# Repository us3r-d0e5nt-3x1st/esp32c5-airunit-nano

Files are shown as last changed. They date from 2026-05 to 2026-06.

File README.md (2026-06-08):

i think it's ready and it should work in the current state, but i still need to check if everything works in practice and write some kind of documentation for it. <br><br>
when you're downloading the files, please use either the main branch > code > download zip, or the project, photos and gerber zip files in the newest release, and not anything in the tags or the source code in the release, because they are older (broken) versions of the project





resources taken mostly from seeed's wiki for xiao s3 sense board + the amazing hx-esp32-cam-fpv project + the esp-cam schematic + the esp32-c5-wroom-1u datasheet + some weird random websites

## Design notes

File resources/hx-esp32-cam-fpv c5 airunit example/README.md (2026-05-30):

it's all documented here, i'm gonna make my design as pin-to-pin compatible with this as possible: https://github.com/RomanLut/hx-esp32-cam-fpv/blob/e0f3d50c493b3d2b5f32726006f0b232bfb88d4a/doc/esp32c5_air_unit.md

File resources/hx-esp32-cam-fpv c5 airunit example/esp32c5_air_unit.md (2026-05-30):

# Building esp32c5 air unit

Unfortunately, there are currently no **esp32c5** boards on the market with a good form factor and a proper camera connector. Using an **esp32c5** as an air unit requires advanced hardware skills and custom assembly. For this reason, the **esp32s3sense** remains the best choice for an air unit for now.

## esp32c5 proof-of-concept air unit

Air unit can be built using **esp32-c5-devkit-c1-N8R4** board, **BY-OV5640** camera adapter and microSD card adapter.

esp32c5_air_unit

Camera and SD card wires should be as short as possible (2-3cm).

**esp32-c5-devkit-c1** board should have at least 4Mb RAM (N8R**4** or more).

esp32c5_air_unit

## esp32c5 DIY air unit

A better air unit can be made using **esp32-c5-wroom-n16-r8** module,  **BY-OV5640** camera adapter and microSD card adapter.
PCB is not designed yet. Module, linear regulator, resistors and capacitors are soldered to piece of copper-clad laminate.

esp32c5_air_unit

esp32c5_air_unit

(on the photo above pcb is marked BY-OV2640 but parts (oscillator, linear regulator) are soldered for BY-OV5640)

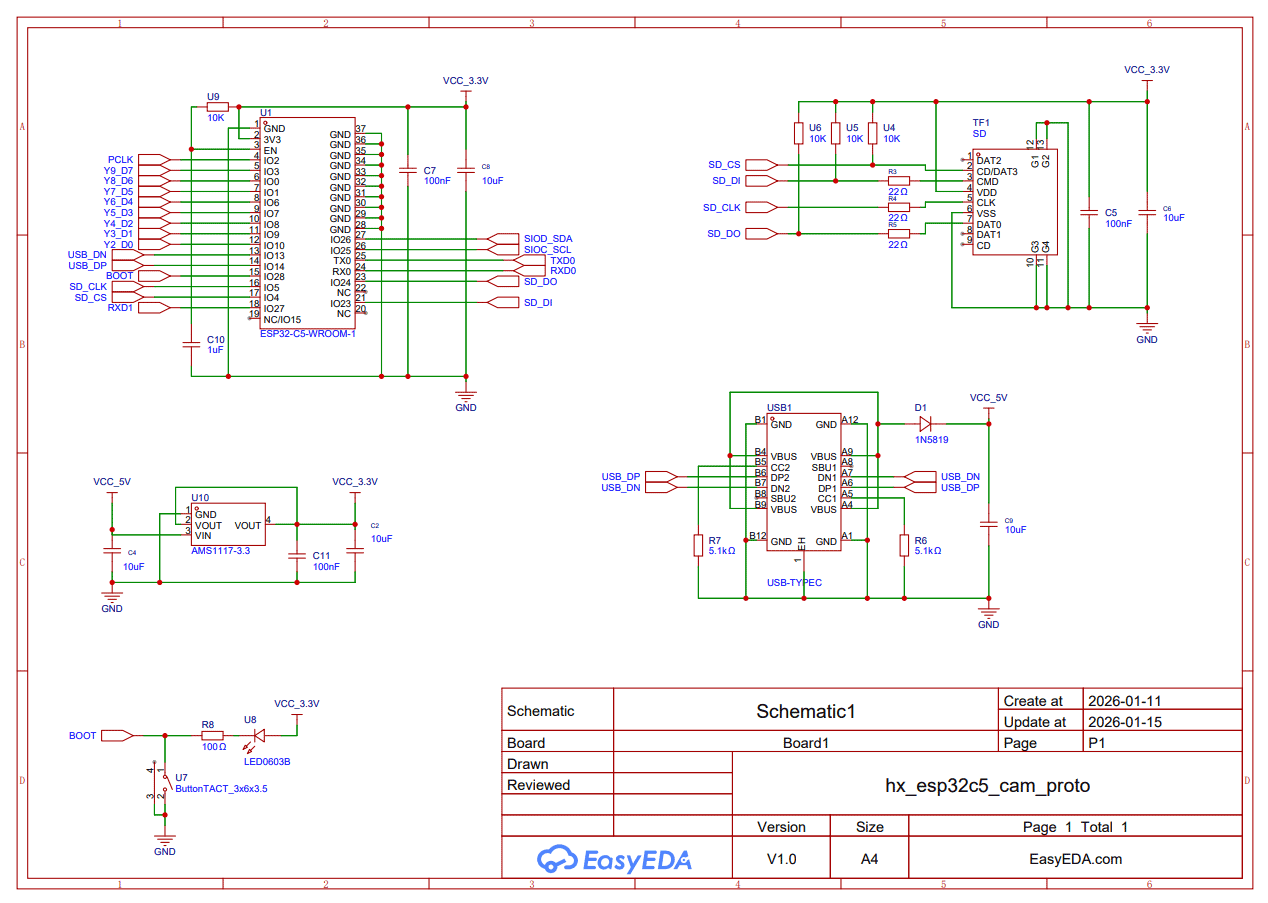
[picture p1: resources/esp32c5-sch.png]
esp32c5_air_unit


[Schematics PDF](/doc/datasheets/esp32c5-prototype-eda.pdf)

[Project EasyEDA](/doc/EasyEDA/hx_esp32c5_cam_proto.eprj)

[3d Printed case on Thingiverse](https://www.thingiverse.com/thing:7292453)

esp32c5_air_unit

esp32c5_air_unit

Size comparison with esp32s3sense:

esp32c5_air_unit

**esp32c5** 1280x720 25fps streaming, recorded on GS:

https://github.com/user-attachments/assets/3dfc3725-5c03-43d9-bf62-a5a76a4a5fef

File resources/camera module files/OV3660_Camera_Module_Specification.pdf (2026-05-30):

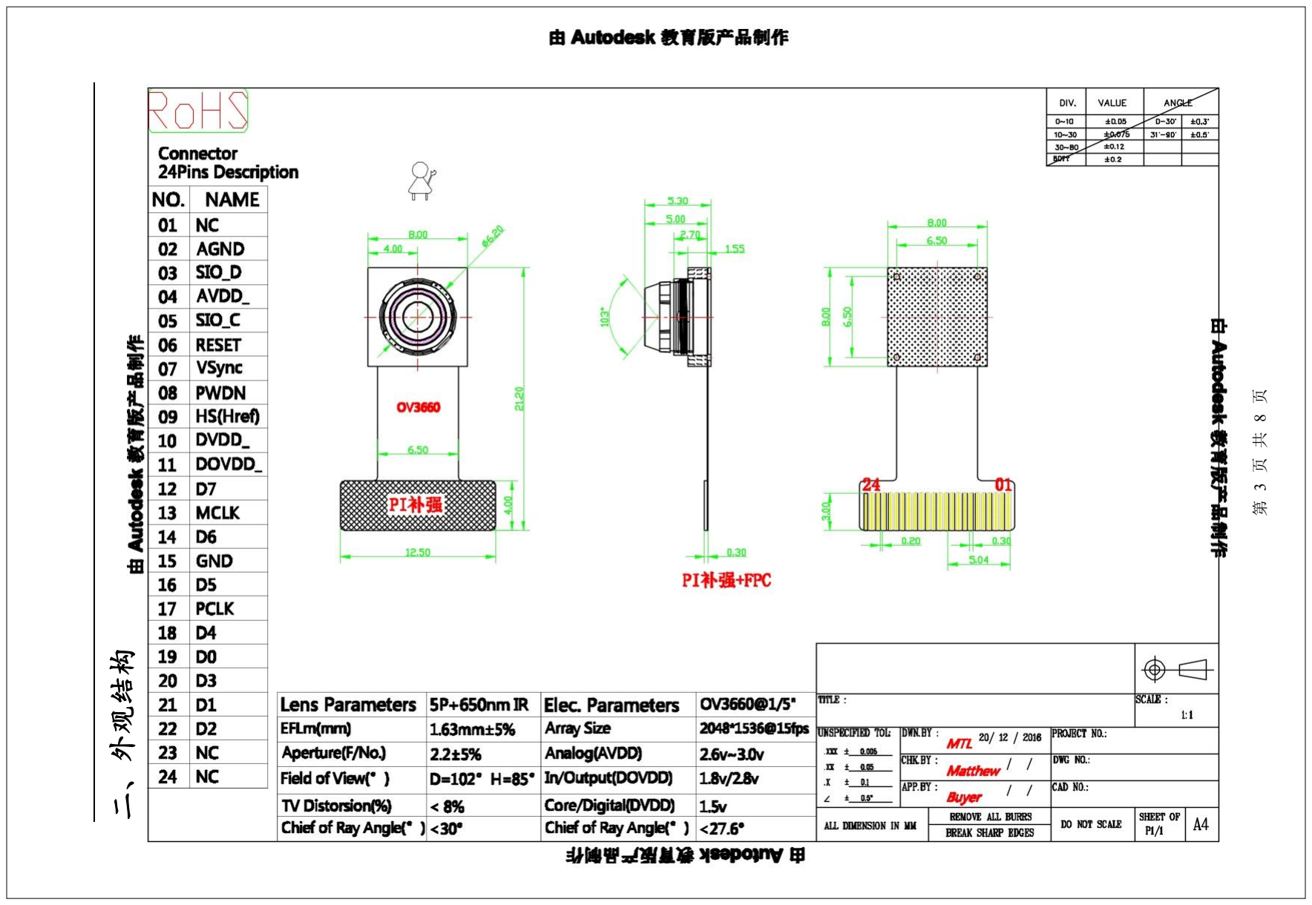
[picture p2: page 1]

## 二、外观结构

第 3 页 共 8 页

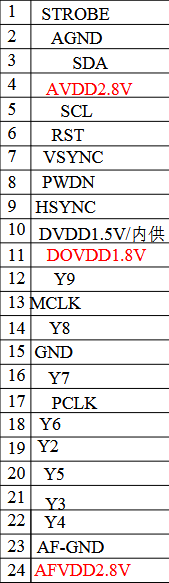
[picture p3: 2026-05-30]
resources/ov5640_pinout.PNG

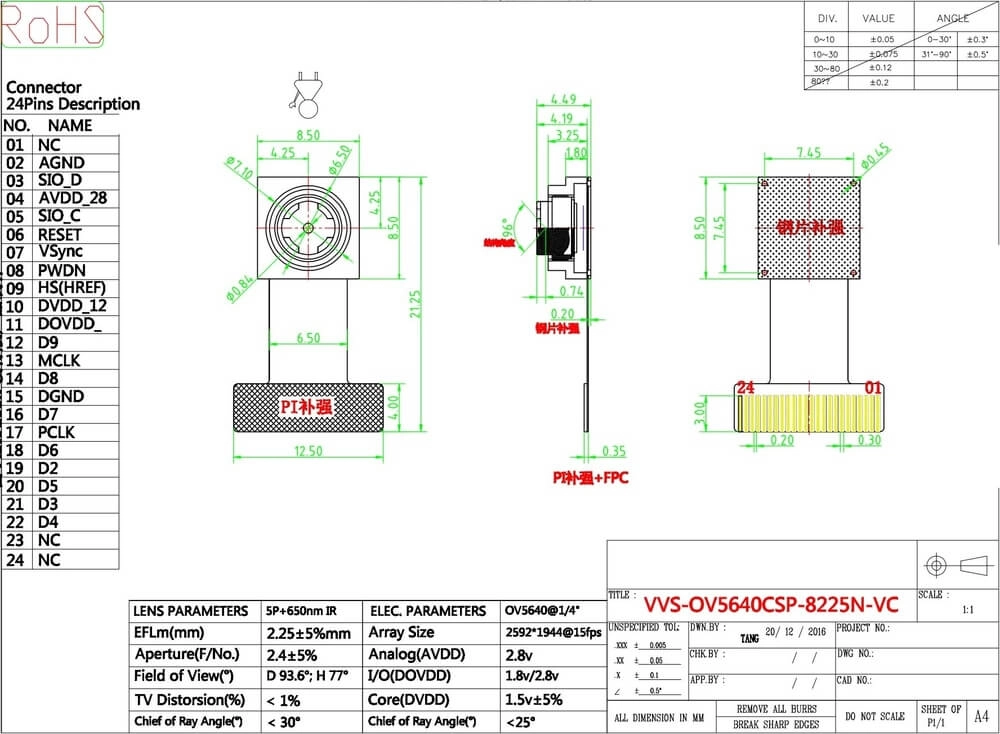
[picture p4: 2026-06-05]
resources/camera module files/ov5460-dimensions.webp

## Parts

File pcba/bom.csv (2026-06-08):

Reference | Qty | Value | Footprint | JLCPCB
C1,C6 | 2 | 100nF 50V | Capacitor_SMD:C_0603_1608Metric | C14663
C2,C3,C4,C5,C8 | 5 | 10uF 10V | Capacitor_SMD:C_0603_1608Metric | C19702
D1 | 1 | RED | LED_SMD:LED_0603_1608Metric | C2286
J1 | 1 | FPC0.5mm-24P | Connector_FFC-FPC:TE_2-1734839-4_1x24-1MP_P0.5mm_Horizontal | C5362165
J8 | 1 | TF-021B-H265 | 0475710001:MOLEX_0475710001 | C498185
L1 | 1 | FHD252010S-100MT | Inductor_SMD:L_Changjiang_FNR252010S | C602007
R1,R6 | 2 | 47kR | Resistor_SMD:R_0603_1608Metric | C25600
R2 | 1 | 12kR | Resistor_SMD:R_0603_1608Metric | C22790
R3 | 1 | 220R | Resistor_SMD:R_0603_1608Metric | C1226
SW1 | 1 | EVQP7C01P | Button_Switch_SMD:SW_SPST_EVQP7C | C388883
U1 | 1 | MT3406 | Package_TO_SOT_SMD:TSOT-23-5 | C22462728

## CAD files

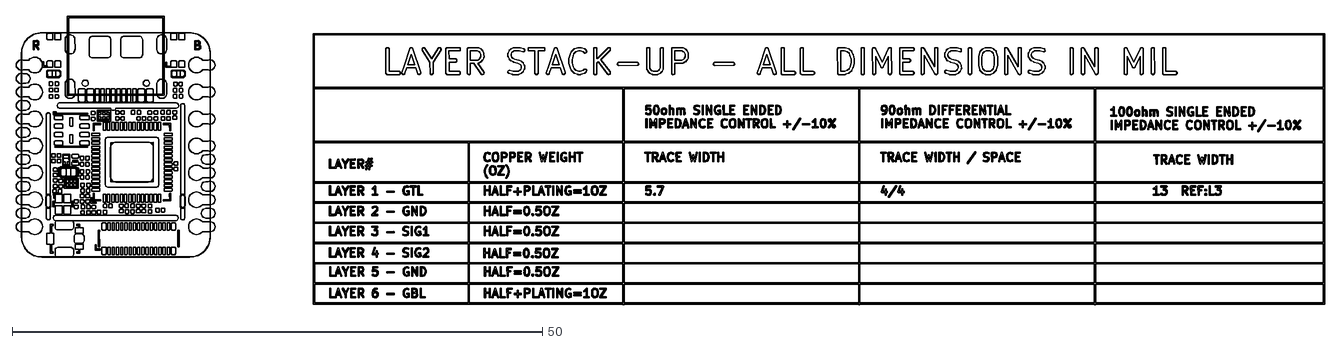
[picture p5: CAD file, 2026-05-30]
resources/xiao s3 resources/s3sense-dimensions.dxf
123.4 x 27.2

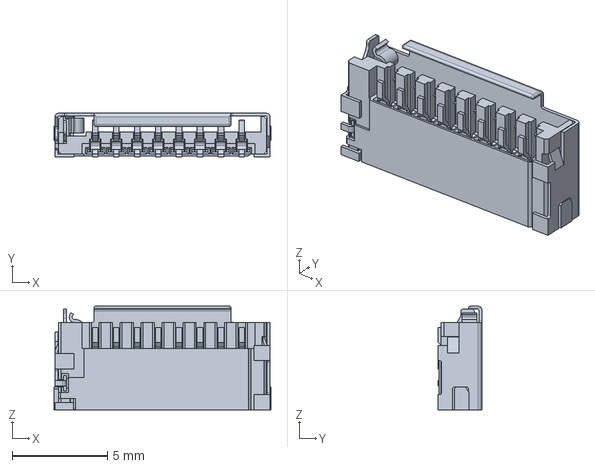
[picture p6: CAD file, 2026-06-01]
project/0475710001/0475710001.stp
11.4 x 2.30 x 5.45 mm

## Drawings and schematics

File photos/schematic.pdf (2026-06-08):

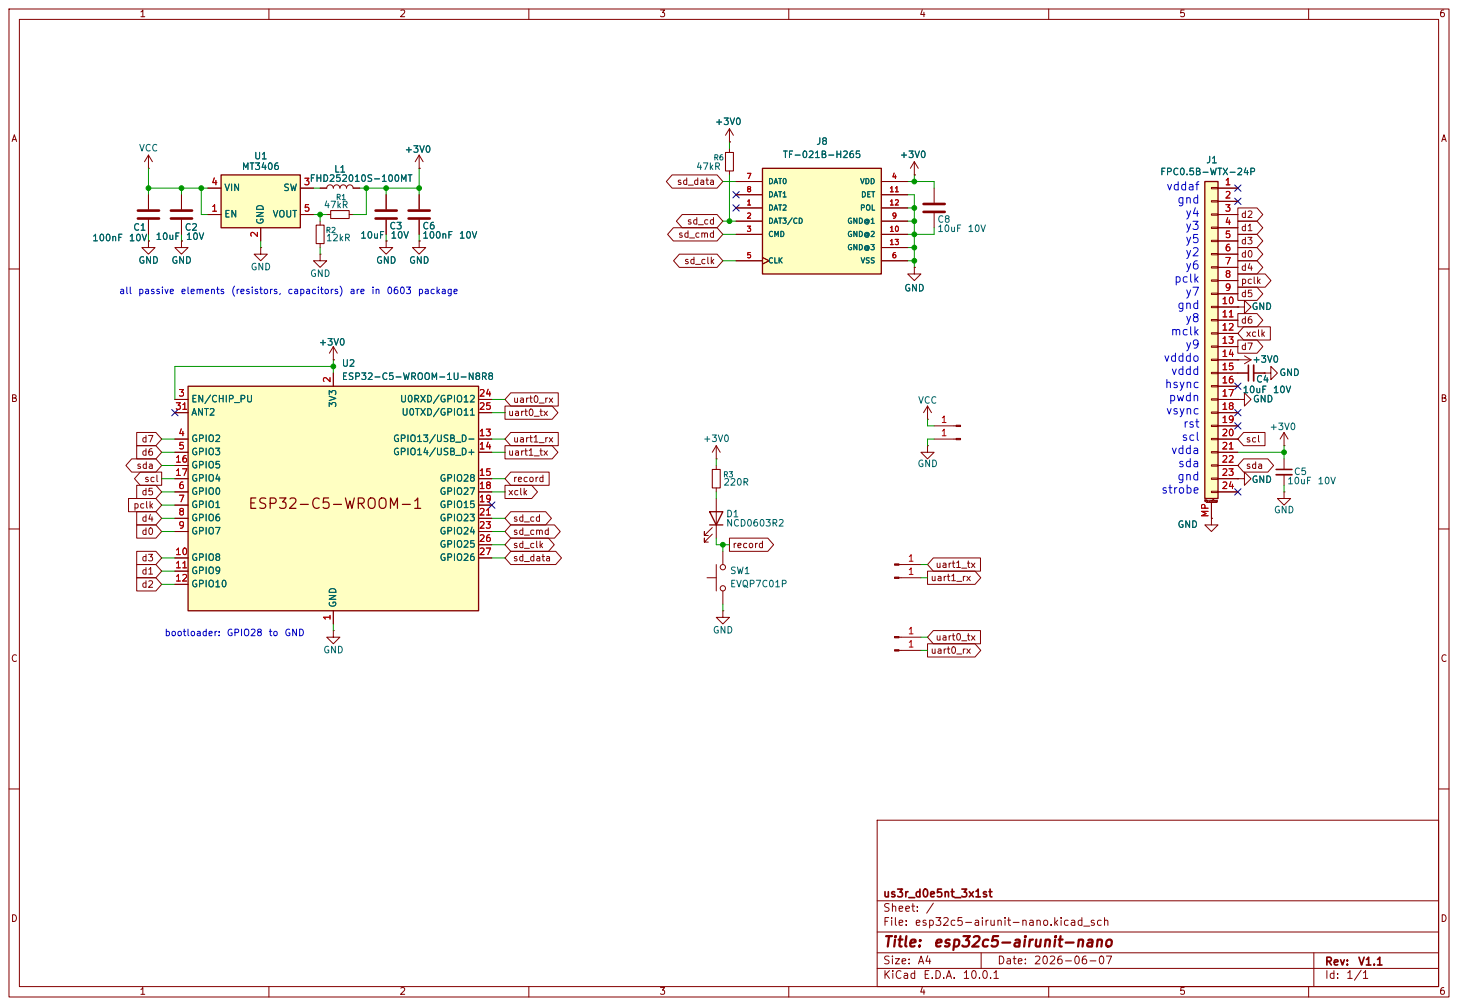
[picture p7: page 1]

uart0_rx uart0_tx uart1_rx uart1_tx all passive elements (resistors, capacitors) are in 0603 package bootloader: GPIO28 to GND

Size: A4 | Rev: V1.1
KiCad E.D.A. 10.0.1 | Id: 1/1

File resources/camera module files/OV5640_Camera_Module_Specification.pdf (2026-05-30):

## 深圳市铭嘉影光电有限公司

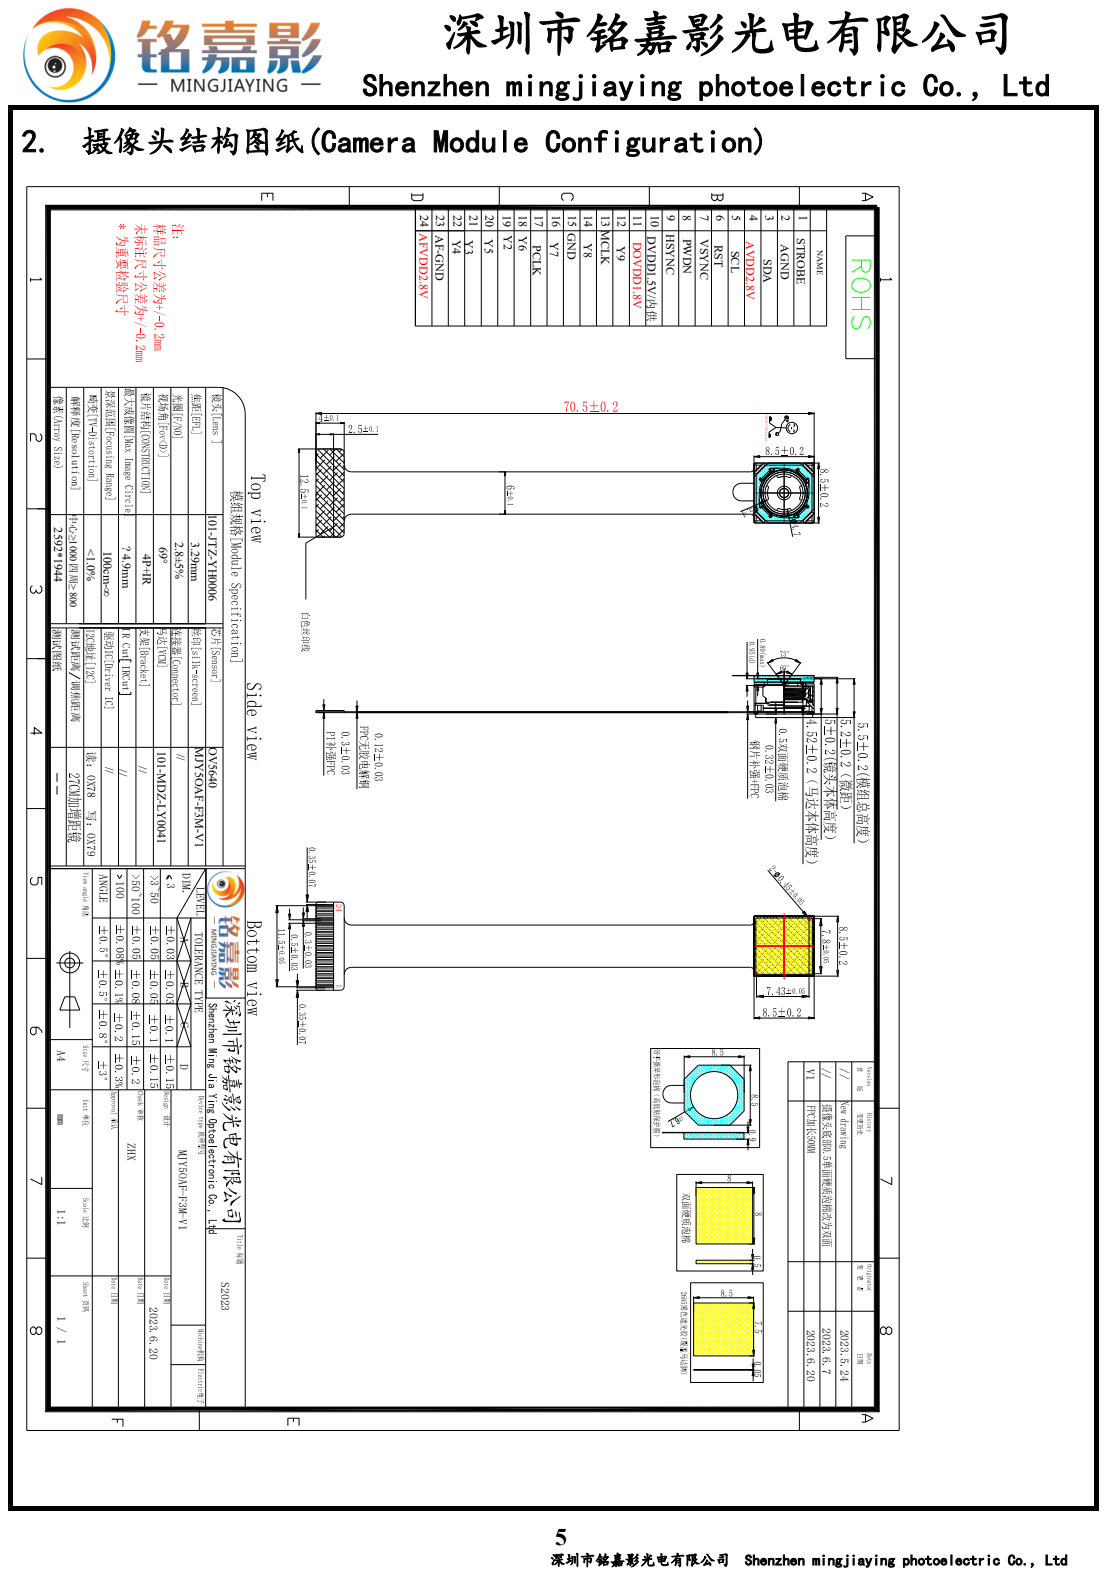
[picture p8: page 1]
TOLERANCE TYPE; ANGLE; LEVEL; DIM. A C D; 101-MDZ-LY0041; 101-JTZ-YH0006; MJY5OAF-F3M-V1; ZHX; AGND 2; SDA 3; AVDD2.8V; STROBE; VSYNC; DVDD1.5V/内供; 11 DOVDD1.8V; 13 MCLK; GND; 23 AF-GND; 24 AFVDD2.8V; SCL; NAME; RST; PWDN; HSYNC; PCLK; 测试图纸

Shenzhen mingjiaying photoelectric Co., Ltd

2. 摄像头结构图纸(Camera Module Configuration)

解释度[Resolution] 测试距离 调焦距离

IR Cut IRCut

深圳市铭嘉影光电有限公司 Shenzhen mingjiaying photoelectric Co., Ltd

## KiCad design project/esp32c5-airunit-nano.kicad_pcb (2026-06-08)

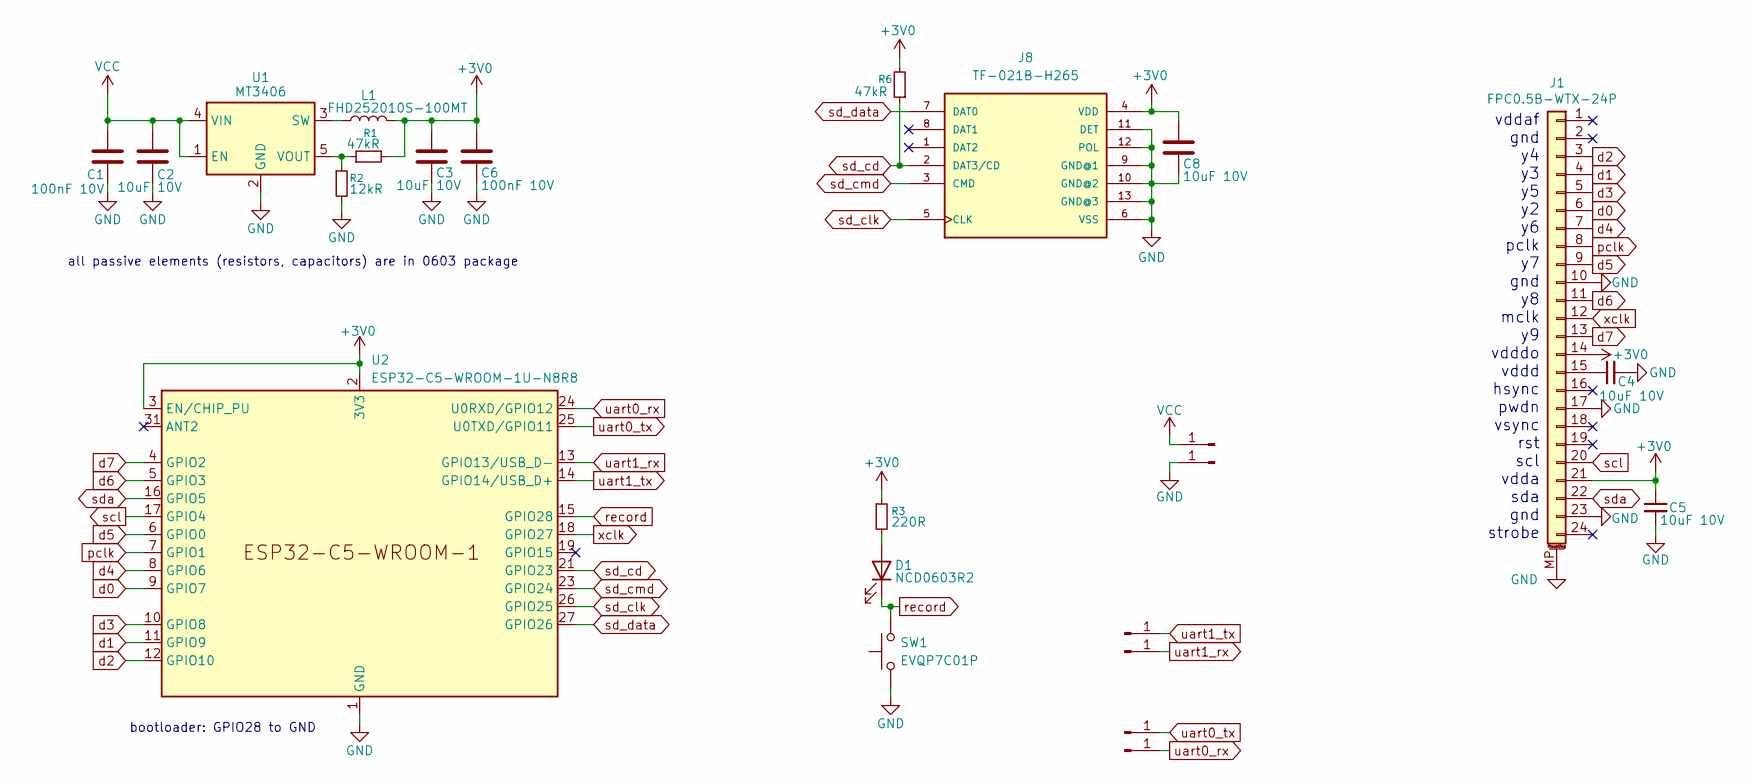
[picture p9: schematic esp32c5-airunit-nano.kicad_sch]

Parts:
C1, C6: 100nF 10V; C_0603_1608Metric
C2, C3, C4, C5, C8: 10uF 10V; C_0603_1608Metric
D1: NCD0603R2; LED_0603_1608Metric
J1: FPC0.5B-WTX-24P; TE_2-1734839-4_1x24-1MP_P0.5mm_Horizontal
J2, J4, J5, J6, J7, J9: Conn_01x01_Pin; SolderWirePad_1x01_SMD_2x3mm
J8: TF-021B-H265; MOLEX_0475710001
L1: FHD252010S-100MT; L_Changjiang_FNR252010S
R1, R6: 47kR; R_0603_1608Metric
R2: 12kR; R_0603_1608Metric
R3: 220R; R_0603_1608Metric
SW1: EVQP7C01P; SW_SPST_EVQP7C
U1: MT3406; TSOT-23-5
U2: ESP32-C5-WROOM-1U-N8R8; ESP32-C5-WROOM-1U

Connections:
+3V0: C3.1, C5.1, C6.1, C8.1, J1.14, J1.21, J8.4 (VDD), L1.2, R1.2, R3.1, R6.2, U2.2 (3V3), U2.3 (EN/CHIP_PU)
GND: C1.2, C2.2, C3.2, C4.2, C5.2, C6.2, C8.2, J1.10, J1.17, J1.23, J1.MP (MountPin), J4.1 (Pin_1_1), J8.6 (VSS), J8.9 (GND@1), J8.10 (GND@2), J8.11 (DET), J8.12 (POL), J8.13 (GND@3), R2.2, SW1.1, U1.2 (GND), U2.1 (GND), U2.28 (GND), U2.29 (GND), U2.30 (GND), U2.32 (GND)
unnamed: D1.2 (A), R3.2
unnamed: C4.1, J1.15
unnamed: L1.1, U1.3 (SW)
unnamed: R1.1, R2.1, U1.5 (VOUT)
VCC: C1.1, C2.1, J2.1 (Pin_1_1), U1.1 (EN), U1.4 (VIN)
d0: J1.6, U2.9 (GPIO7)
d1: J1.4, U2.11 (GPIO9)
d2: J1.3, U2.12 (GPIO10)
d3: J1.5, U2.10 (GPIO8)
d4: J1.7, U2.8 (GPIO6)
d5: J1.9, U2.6 (GPIO0)
d6: J1.11, U2.5 (GPIO3)
d7: J1.13, U2.4 (GPIO2)
pclk: J1.8, U2.7 (GPIO1)
record: D1.1 (K), SW1.2, U2.15 (GPIO28)
scl: J1.20, U2.17 (GPIO4)
sd_cd: J8.2 (DAT3/CD), R6.1, U2.21 (GPIO23)
sd_clk: J8.5 (CLK), U2.26 (GPIO25)
sd_cmd: J8.3 (CMD), U2.23 (GPIO24)
sd_data: J8.7 (DAT0), U2.27 (GPIO26)
sda: J1.22, U2.16 (GPIO5)
uart0_rx: J5.1 (Pin_1_1), U2.24 (U0RXD/GPIO12)
uart0_tx: J6.1 (Pin_1_1), U2.25 (U0TXD/GPIO11)
uart1_rx: J9.1 (Pin_1_1), U2.13 (GPIO13/USB_D-)
uart1_tx: J7.1 (Pin_1_1), U2.14 (GPIO14/USB_D+)
xclk: J1.12, U2.18 (GPIO27)

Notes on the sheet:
bootloader: GPIO28 to GND
all passive elements (resistors, capacitors) are in 0603 package
vddaf gnd y4 y3 y5 y2 y6 pclk y7 gnd y8 mclk y9 vdddo vddd hsync pwdn vsync rst scl vdda sda gnd strobe

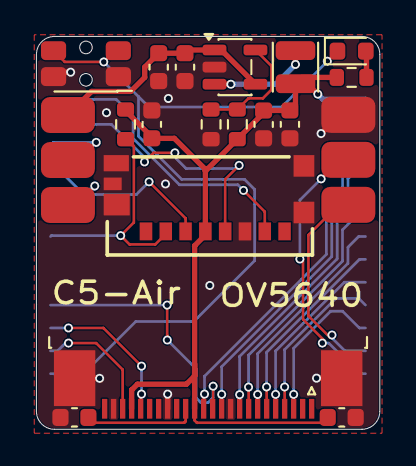
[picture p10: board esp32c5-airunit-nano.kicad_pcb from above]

Board: 2 copper layers, 19.1 x 21.8 mm, 24 parts (1 on the bottom side), 28 nets.

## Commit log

2026-05-30 i've added some resources to help me create this project
    [s3sense-dimensions.dxf]
2026-05-30 i've added some VERY early project files
    tbh just some preparations for creating a project, not much more
    [esp32c5-airunit-nano.kicad_pcb, esp32c5-airunit-nano.kicad_sch]
2026-05-30 i've added a part of ov5640 datasheet and copied the airunit example description from the hx-esp32-cam-fpv project
2026-05-30 i've deleted this folder cause it's all in the /camera module files directory
2026-05-30 i've updated the project files
    ! ! ! STILL UNFINISHED ! ! !
    [esp32c5-airunit-nano.kicad_pcb, esp32c5-airunit-nano.kicad_sch]
2026-06-01 i've updated the project files
    we're actually getting somewhere, the layout is pretty close to what i would call not bad
    [0475710001.stp, Micro SD Card.STEP, esp32c5-airunit-nano.kicad_pcb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]
2026-06-05 i've uploaded the final project
    [0475710001.stp, esp32c5-airunit-nano.kicad_pcb, esp32c5-airunit-nano.kicad_sch]
2026-06-05 i've updated the schematic and changed the button for a cheaper one
    [esp32c5-airunit-nano-B_Cu.gbr, esp32c5-airunit-nano-B_Mask.gbr, esp32c5-airunit-nano-B_Paste.gbr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]
2026-06-05 the R2 should be 25kR
    [esp32c5-airunit-nano.kicad_sch]
2026-06-05 i've added a note in the readme
    the R2 should be +/- 25kR, and not 22kR, we need 3.0V and not 3.3V
2026-06-05 i've updated the pcb screenshot in the readme
2026-06-07 i've updated the files
    there were some major errors in the v1.0 of the project
    [esp32c5-airunit-nano-B_Cu.gbr, esp32c5-airunit-nano-B_Mask.gbr, esp32c5-airunit-nano-B_Paste.gbr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]
2026-06-07 i've updated the schematic in readme file
    it's actually v1.1, the bugfix, just forgot to change the version mark in the schematic
2026-06-08 i've uploaded the v1.2
    [esp32c5-airunit-nano-B_Cu.gbr, esp32c5-airunit-nano-B_Mask.gbr, esp32c5-airunit-nano-B_Paste.gbr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]
2026-06-08 i've added the BOM and Pick&Place files needed for PCBA
    [bom.csv, pickandplace.csv]
2026-06-09 i've deleted the old c5-air-gerber.zip file that was left in the repo somewhere
